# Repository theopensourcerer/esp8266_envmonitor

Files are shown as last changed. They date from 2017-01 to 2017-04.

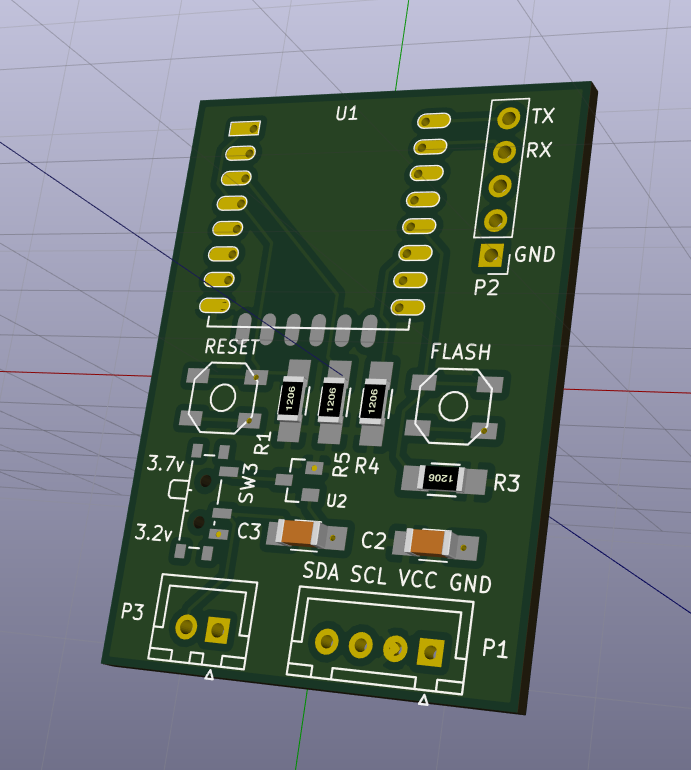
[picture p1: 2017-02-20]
pcb/environment-monitor-1.4.png

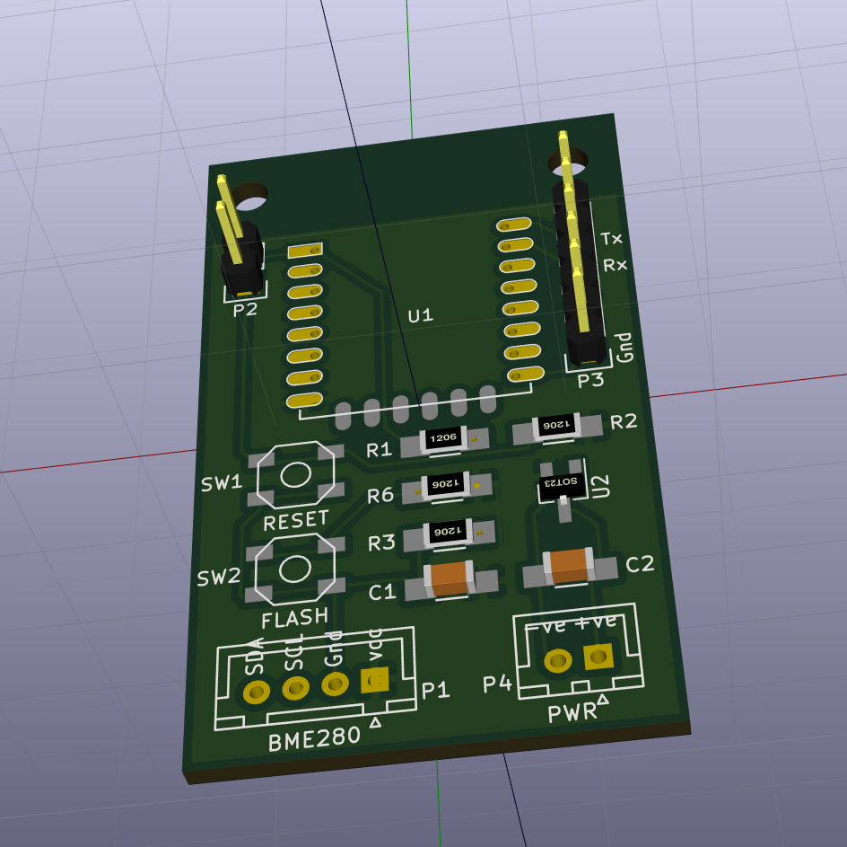
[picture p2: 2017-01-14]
pcb/environment-monitor-1.2.png

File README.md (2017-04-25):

# ESP8266 Environment Monitor

## Table of Contents
* [Summary](#summary)
* [Case](#case)
* [Hardware](#hardware)
* [Code](#code)
* [License](#license)

## Summary
This is a personal project to build an Environment Monitor for my Polytunnel where I mostly grow chillies.

The project consists of three parts: the case to hold the monitor, the hardware (PCB and Sensor(s) etc.) and the software.

## Case

The case is designed in OpenSCAD and is suitable for printing on a 3D Printer. I am very pleased with the results of the design. Please feel free to use and improve - within the terms of the license of course.

## Hardware

The Schematic and PCB are designed in KiCAD. The board has not yet been fully tested. In fact the board has several flaws, some of which do not seem to be problematic, but one that caused me a long headache. The pin called CH_PD on my board needed to be pulled high. I have tacked a 4.7k resistor to the back of the board. Without this, the board would not start. Oddly though, in all of the previous ESP8266 designs I have worked on (mostly on vero or breadboard) I have not had to pull this pin high at all. Please be __warned__ if you want to use my design.

As of version 1.4 of the schematic and PCB the above issue should be fixed. I've not tested it but the board has undergone a fairly major redesign which includes an on-board switch to support for running directly of LiFePO4 batteries at 3.2v or, via the Regulator off normal 3.7v Li-ion.

## Code

The software for the ESP8266 is in this directory. It is fairly simple C code. The config.h file contains user-defined parameters.
The ESP8266 code works like this: On power up the ESP attempts to connect to the WiFi network. If successful it then attempts to 
read the data back from the BME280 which provides, Temperature, Humidity and Pressure information. If the BME is read successfully
the data is formatted and sent to the MQTT broker. The ESP8266 also sends infomration about it's supply voltage and the time it 
took to run this code loop. Finally the code puts the ESP into "Deep Sleep" for a preconfigured period.

## License

The software is GPL, the OpenSCAD design of the case is Creative Commons Attribution-ShareAlike 4.0 International and the 
electronic designs are licenced using the Solderpad Hardware License version 0.51

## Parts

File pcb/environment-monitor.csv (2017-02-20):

Reference | Value | Footprint | Datasheet | BOM
U1 | ESP-12F | ESP8266:ESP-12E
R1 | 4.7k | Resistors_SMD:R_1206_HandSoldering
R3 | 4.7k | Resistors_SMD:R_1206_HandSoldering
C2 | 10uF | Capacitors_SMD:C_1206_HandSoldering
P1 | BME280 | Connectors_JST:JST_XH_B04B-XH-A_04x2.50mm_Straight
P3 | PWR | Connectors_JST:JST_XH_B02B-XH-A_02x2.50mm_Straight
SW1 | RESET | switches:SKQGAFE010_Switch
SW2 | FLASH | switches:SKQGAFE010_Switch
R4 | 4.7k | Resistors_SMD:R_1206_HandSoldering
C3 | 1uF | Capacitors_SMD:C_1206_HandSoldering
U2 | MCP1700T | smd-semi:SOT-23 |  | IC MICROCHIP MCP1700T-vv02E/TT
R5 | 4.7k | Resistors_SMD:R_1206_HandSoldering
SW3 | Switch_SPDT_x2 | switches:SW_SPDT_PCM12
P2 | SERIAL | Pin_Headers:Pin_Header_Straight_1x05_Pitch2.54mm

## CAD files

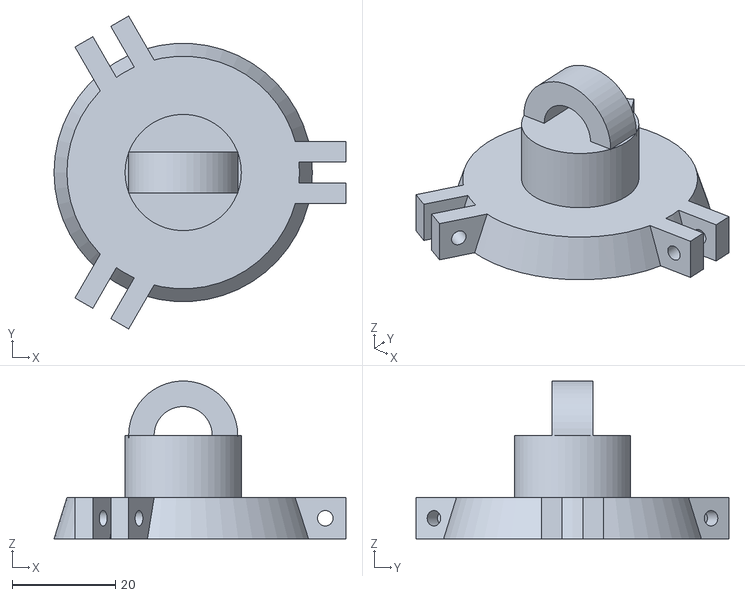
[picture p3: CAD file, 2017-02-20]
case/grabber-top.stl
56.5 x 60.6 x 30.5

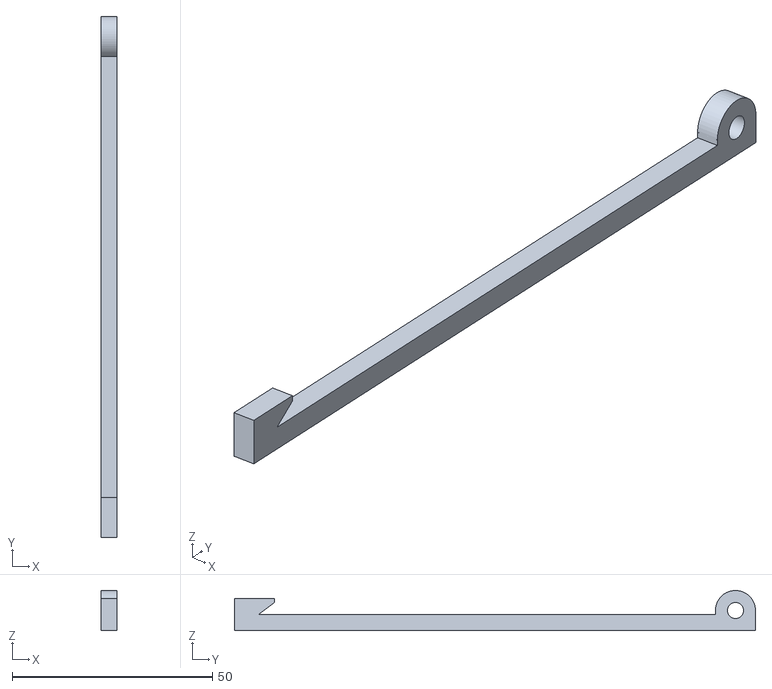
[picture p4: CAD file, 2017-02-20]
case/grabber-leg.stl
4.00 x 130.0 x 10.0

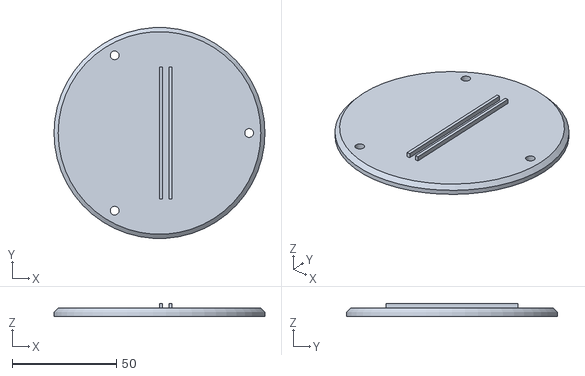
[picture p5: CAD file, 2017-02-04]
case/base.stl
101.0 x 100.8 x 6.00

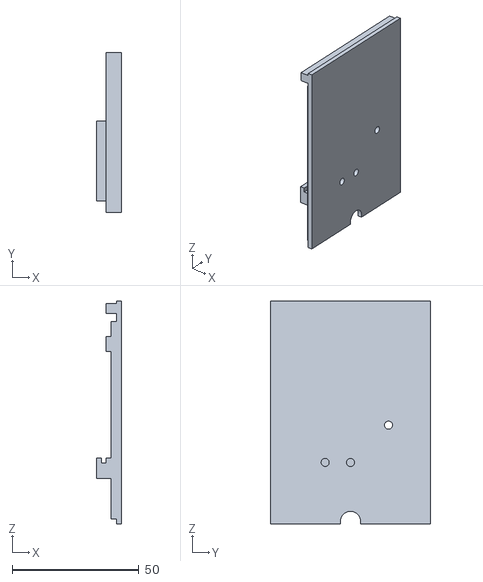
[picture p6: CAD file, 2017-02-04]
case/mounting-plate.stl
9.75 x 63.0 x 88.0

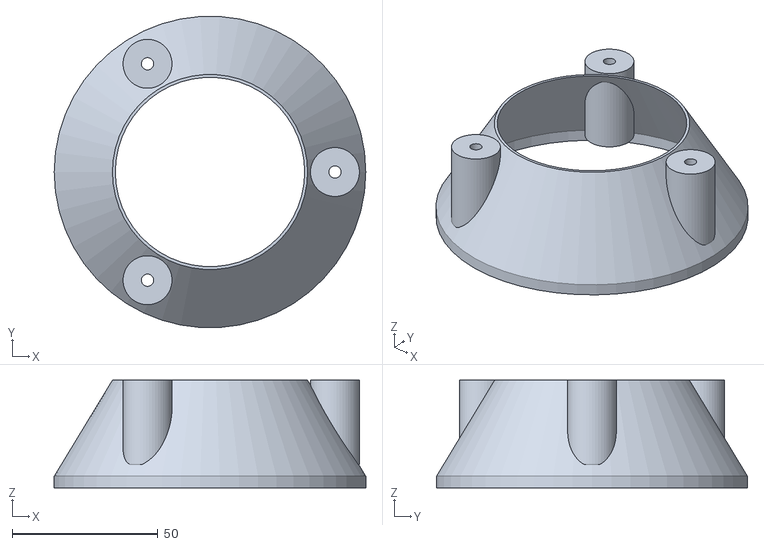
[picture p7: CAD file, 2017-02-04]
case/other-sections.stl
107.0 x 106.8 x 37.0

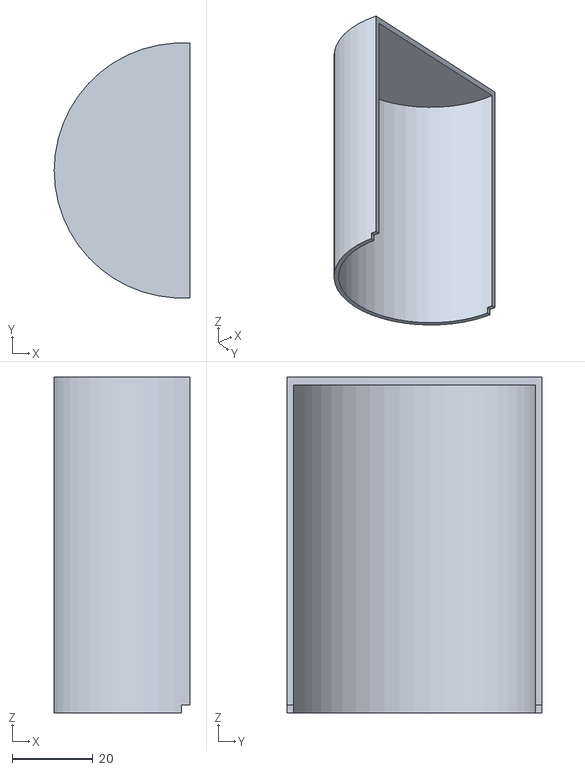
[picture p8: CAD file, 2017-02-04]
case/internal-case.stl
33.5 x 62.9 x 83.0

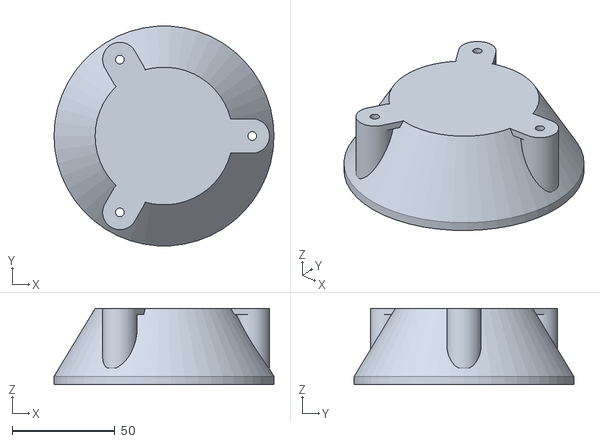
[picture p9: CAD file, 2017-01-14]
case/top-section.stl
107.0 x 106.8 x 37.0

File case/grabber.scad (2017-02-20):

/*
 * Grabber
 */
$fn=50;
width = 4;
depth = 4;
length = 120;

bracketLength=13;
topdia = 45;
bottomdia = 50;

top();

leg();
module leg() {
    cube([width,length,depth]);
    translate([0,,0,depth]) {
        gripper();
    }
    translate([0,length,0]) {
        brace();
    }
 }
 
module gripper() {
    gripper=10;
    difference() {
        cube([width,gripper,depth]);
        translate([0,gripper-depth,0]) {
            prism(width,depth,depth-1);
        }
    }
}

module brace() {
    brace=10;
    difference() {
        union() {
            translate([0,brace/2,brace/2]) {
                rotate([0,90,0]) cylinder(d=10,h=depth);
            }
            cube([width,brace,brace/2]);
        }
        translate([0,brace/2,brace/2]) {
            rotate([0,90,0]) cylinder(d=width,h=depth*2);
        }
    }
}

module top() {
    height=depth*2;
    cylinder(d1=bottomdia,d2=topdia,h=height);
    for(r=[0,120,240]) rotate([0, 0, r]) translate([topdia/2-depth,0, 0]) bracket();
    hook();
}

module bracket() {
    translate([0,-(depth+(depth/2)),0]) {
        difference(){
            cube([bracketLength,depth*3,depth*2]);
            translate([0,depth,0]) {
                cube([bracketLength,depth,depth*2]);
            }
            translate([bracketLength-depth,depth*3.5,depth]) {
                rotate([90,0,0]) cylinder(d=3,h=depth*4);
            }
        }
    }
}

module prism(l, w, h){
    polyhedron(
        points=[[0,0,0], [l,0,0], [l,w,0], [0,w,0], [0,w,h], [l,w,h]],
        faces=[[0,1,2,3],[5,4,3,2],[0,4,5,1],[0,3,4],[5,2,1]]
    );
}

module hook() {
    cylinder(d=topdia/2,h=depth*5);
    translate([0,depth,depth*5]) {
        difference() {
            rotate([90,0,0]) cylinder(d=topdia/2.13,h=depth*2);
            rotate([90,0,0]) cylinder(d=topdia/4,h=depth*2.1);
        }
    }
}

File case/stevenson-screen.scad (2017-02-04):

/**
 * Design for a Stevenson Screen type container
 *
 * License:  Attribution-ShareAlike 4.0 International 
 * https://creativecommons.org/licenses/by-sa/4.0/
 *
 * Based on an original idea from http://jeelabs.net/boards/6/topics/1857
 *
**/


/*
 * makeBase:base,
   makeBottom:bottom,
   makeMiddle:middle,
   makeTop,top,
   makeAll:all
 *
**/
part = "makeAll"; 

$fn=50;
id=65;
od=105;
sectionheight=33;
walls=2;
bolt=4.2;
top_depth=walls+1;
pillar_radius = (id/2)+(bolt*walls)+walls;
pillarheight=(sectionheight-(walls*2));
containerHeight = 83;

nutSize = 6;
nutHeight = 3;
nutThread = 3.2;
boltLength = 8;

pcbWidth = 31.5;
pcbHeight = 52.5;
pcbThickness = 1.75;
pcbHoleCentres = 24;

// Base
//base();

mountingPlate();
/*
internalCase();

// Bottom Section
color("DeepSkyBlue", 0.5) translate([0,0,walls*2]) {
    difference() {
        section();
        translate([pillar_radius,0,0]) {
            bolthole();        }
        translate([-pillar_radius/2,((pillar_radius)*sin(120)),0]) {
            bolthole();
        }
        translate([-pillar_radius/2,-((pillar_radius)*sin(120)),0]) {
            bolthole();
        }
    }
}

//Middle Section
color("DeepSkyBlue", 0.5) translate([0,0,sectionheight]) {
    difference() {
        section();
        translate([pillar_radius,0,0]) {
            bolthole();        }
        translate([-pillar_radius/2,((pillar_radius)*sin(120)),0]) {
            bolthole();
        }
        translate([-pillar_radius/2,-((pillar_radius)*sin(120)),0]) {
            bolthole();
        }
    }
}


// Top Section
%translate([0,0,sectionheight*2-(walls*2)]) {
    difference() {
        section();
        translate([pillar_radius,0,0]) {
            bolthole();
        }
        translate([-pillar_radius/2,((pillar_radius)*sin(120)),0]) {
            bolthole();
        }
        translate([-pillar_radius/2,-((pillar_radius)*sin(120)),0]) {
            bolthole();
        }
    }
}

// Top
color("DeepSkyBlue", 0.5) translate([0,0,sectionheight*3-(top_depth*2+1)]) top();
*/
module section() {
    difference() {
        cylinder(sectionheight,(od+walls)/2,(id+walls)/2 );
        cylinder(sectionheight,(od/2),(id/2));
    }
    // Skirt
    translate([0,0,-walls*2]) {
        difference() {
            cylinder(walls*2,(od+walls)/2,(od+walls)/2);
            cylinder(walls*2,od/2,od/2);
        }
    }
    translate([pillar_radius,0,0]) {
         pillar();
    }
    translate([-pillar_radius/2,((pillar_radius)*sin(120)),0]) {
        pillar();
    }
    translate([-pillar_radius/2,-((pillar_radius)*sin(120)),0]) {
        pillar();
    }    
}

module pillar() {
    translate([0,0,walls*2]) {
        difference(){
            cylinder(pillarheight,bolt*walls, bolt*walls);
            bolthole();
        }
    }
}

module bolthole() {
    cylinder(pillarheight,bolt/2,bolt/2);
}

module base() {
    base_thickness=walls;
    difference() {
        union() {
            cylinder(base_thickness,(od-4)/2,(od-4)/2);
            translate([0,0,base_thickness]) {
                cylinder(base_thickness,(od-4)/2,(od-8)/2);
            }
            translate([0,-((id-walls)/2),base_thickness*2]) divider();
        }
        translate([pillar_radius,0,0]) {
            bolthole();
        }
        translate([-pillar_radius/2,((pillar_radius)*sin(120)),0]) {
            bolthole();
        }
        translate([-pillar_radius/2,-((pillar_radius)*sin(120)),0]) {
            bolthole();
        }
    }
}

module top() {
    cylinder(top_depth,(id+walls)/2,(id+walls)/2);
    translate([pillar_radius,0,0]) {
        lobe();
    }
    translate([-pillar_radius/2,((pillar_radius)*sin(120)),0]) {
        rotate(120) lobe();
    }
    translate([-pillar_radius/2,-((pillar_radius)*sin(120)),0]) {
        rotate(-120) lobe();
    }
    translate([0,-((id-walls)/2),top_depth-(walls*2)]) divider();
}

module lobe() {
    difference(){
        hull() {
            cylinder(top_depth,bolt*walls, bolt*walls);
            translate([-bolt*walls,0,0]) {
                cylinder(top_depth,bolt*walls, bolt*walls);
            }
        }
        cylinder(top_depth,bolt,bolt);
    }
}
module divider() {
    widthOfBaseBlock=walls*3;
    difference() {
        cube([widthOfBaseBlock,id-walls,walls]);
        translate([(widthOfBaseBlock/4),0,0]){
            cube([walls+(walls/2),id-walls,walls*2]);
        }
    }
}

module mountingPlate() {
    difference() {
        union() {
            // Plate
            translate([walls,-((id-walls)/2), walls*2]) {
                cube([walls,id-walls,(pillarheight*3)+(walls/2)]);
            }
            // External top bar
            translate([-walls,-((id-walls)/2), containerHeight+(walls*2)]) {
                cube([walls*2, id-walls,walls*2]);
            }
            // Side bar
            translate([0,-((id-walls)/2)+walls,walls*3]) {
                cube([walls,walls,containerHeight-walls*2.5]);
            }
            // Side bar
            translate([0,((id-walls)/2)-(walls*2),walls*3]) {
                cube([walls, walls,containerHeight-walls*2.5]);
            }
            // Internal top bar
            translate([0,-(id-(walls*5))/2,containerHeight-(walls-1)]) {
                cube([walls,id-(walls*5), walls]);
            }
            // PCB top mount
            translate([walls,-27,(walls*2)+74]) {
                rotate([0,180,0]) {
                    pcbTopMount();
                }
            }
            translate([walls,-27,(walls*2)+(74-50)]) {
                rotate([0,180,0]) {
                    pcbBottomMount();
                }
            }
        }
        // Battery case mounting hole
        translate([walls-1,((id-walls)/2)-(walls*2)-11-(3/2),(walls*2)+39]) {
            rotate([0, 90,0]) {
                cylinder(d=3.2,h=walls+2);
            }
        }
        // Sensor cable access
        translate([walls-1,0,5]) {
            rotate([0,90,0]){
                cylinder(d=8,h=walls+2);
            }
        }
        // BME280 mounting holes
        translate([-1,0,(walls*2)+24.3]) {
            rotate([0,90,0]) {
                cylinder(d=3.2,h=walls+2);
                bolt(nutSize,nutHeight, nutThread,boltLength);

                translate([0,-10,0]) {
                    cylinder(d=3.2,h=walls+2);
                bolt(nutSize,nutHeight, nutThread,boltLength);

                }
            }
        }
    }
}

module internalCase() {
    odia = id-walls;
    idia = id-(walls*2.5);
    translate([0, 0, walls*2]) {        
        difference() {
            cylinder(h=containerHeight,d1=odia,d2=odia);
            cylinder(h=containerHeight-walls,d1=idia,d2=idia);
            translate([walls,-id/2,0]) {
                cube([id/2, id, containerHeight]);
            }
            translate([0,-odia/2,0]) {
                cube([walls,odia,walls]);
            }  
        }
    }
}

module pcbTopMount() {
    diff = (pcbWidth-pcbHoleCentres) / 2;
    difference() {
        cube([nutHeight+1,pcbWidth,nutSize]);
        translate([0,diff,(nutThread/2)]){
            rotate([0,90,0]) {
                bolt(nutSize,nutHeight, nutThread,boltLength,true);
            }
        }
        translate([0,(pcbWidth-diff),(nutThread/2)]){
            rotate([0,90,0]) {
                bolt(nutSize,nutHeight, nutThread,boltLength, true);
            }
        }
    }
}

module pcbBottomMount() {
        translate([0,0,-2]) {
            cube([nutHeight+1,pcbWidth,nutSize+2]);
        }
        translate([nutHeight+1,0,0]) {
            cube([pcbThickness,pcbWidth,nutSize]);
        }
        translate([nutHeight+1+pcbThickness,0,-2]) {
            cube([walls,pcbWidth,nutSize+2]);
        }
}

// Nut
module nut(width,height,thread) {
    difference() {
        cylinder(d=width/(cos(180/6)), h=height, $fn=6);
        translate([0,0,-0.5]) {
            cylinder(d=thread,h=height+1);
        }
    }
}

module bolt(width,height,thread,length,hull) {
    cylinder(d=width/(cos(180/6)), h=height, $fn=6);
    if(hull) {
        hull(){
            translate([0,0,height]) {
                cylinder(d=thread,h=length);
            }
            translate([thread,0,height]) {
                cylinder(d=thread,h=length);
            }
        }
    } else {
        translate([0,0,height]) {
            cylinder(d=thread,h=length);
        }
    }
}

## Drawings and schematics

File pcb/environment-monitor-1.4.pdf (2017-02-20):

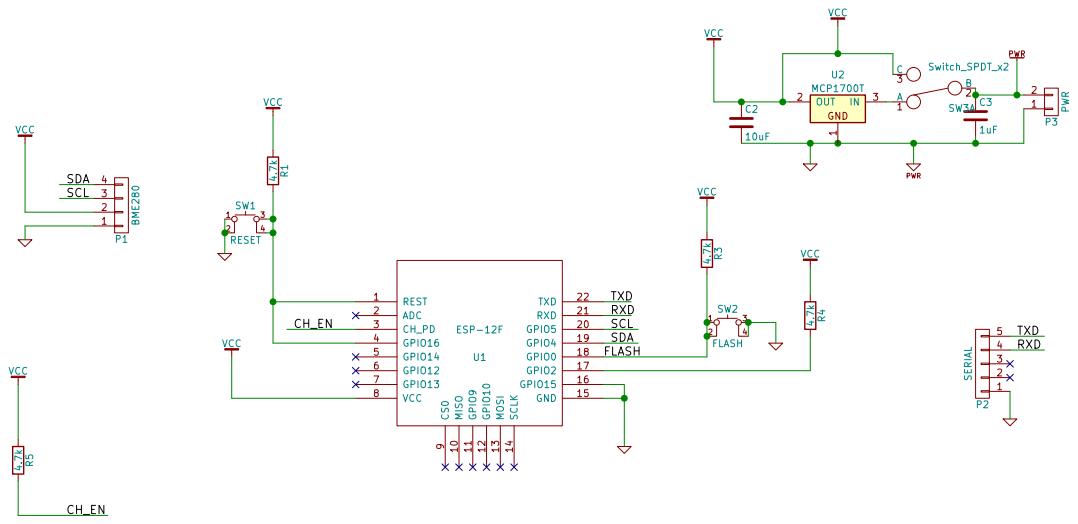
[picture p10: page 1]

9 MISO 10 GPIO5 20 GPIO9 11 RXD 21 GPIO10 12 TXD 22 MOSI 13 SCLK 14 GND 15 GPIO15 16 GPIO2 17 GPIO0 18 GPIO4 19 U1 ESP-12F R1 4.7k R3 4.7k C2

Contact: alanslists@gmail.com
Id: 1/1 Title: Environment Monitor File: environment-monitor.sch Sheet: / Solderpad Hardware License version 0.51

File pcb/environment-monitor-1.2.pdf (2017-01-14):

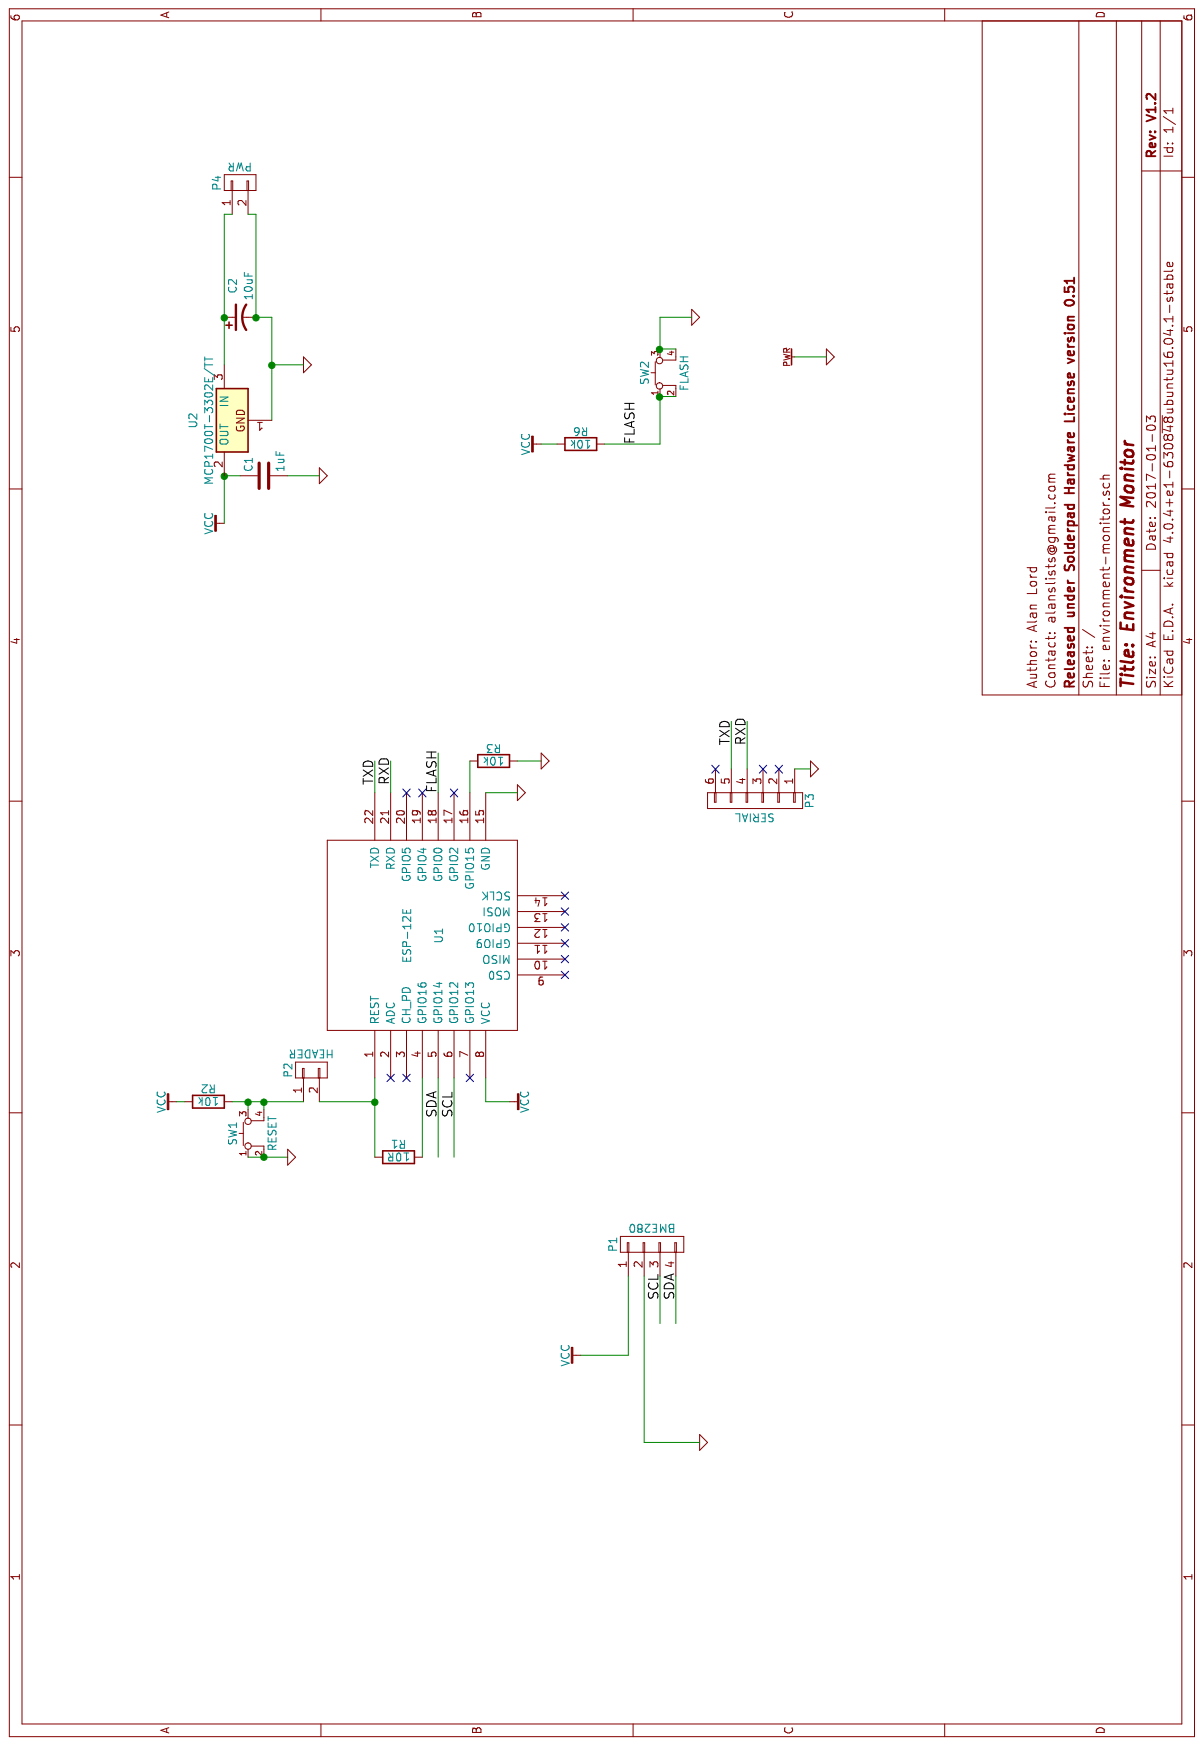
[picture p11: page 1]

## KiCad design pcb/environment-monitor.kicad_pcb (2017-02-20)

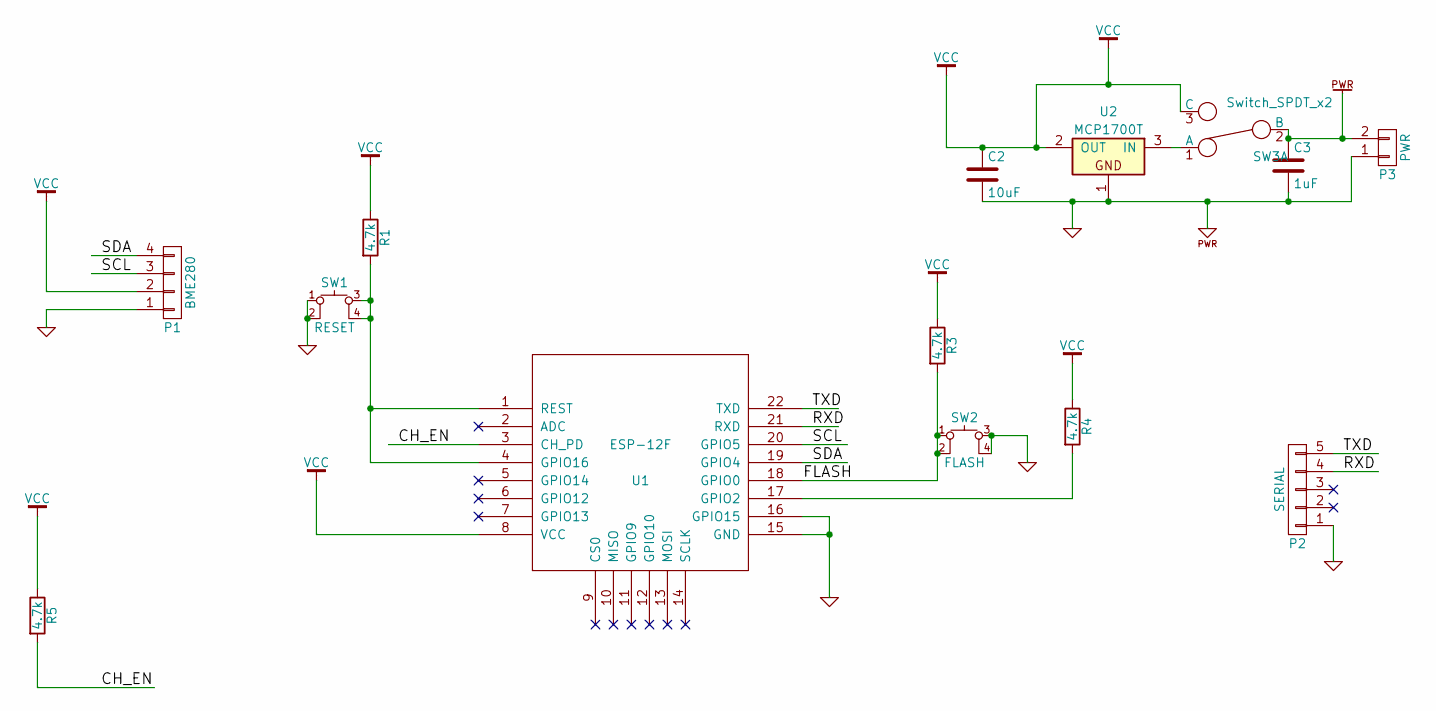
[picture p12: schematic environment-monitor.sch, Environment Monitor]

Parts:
C2: 10uF; C_1206_HandSoldering
C3: 1uF; C_1206_HandSoldering
P1: BME280; JST_XH_B04B-XH-A_04x2.50mm_Straight
P2: SERIAL; Pin_Header_Straight_1x05_Pitch2.54mm
P3: PWR; JST_XH_B02B-XH-A_02x2.50mm_Straight
R1, R3, R4, R5: 4.7k; R_1206_HandSoldering
SW1: RESET; SKQGAFE010_Switch
SW2: FLASH; SKQGAFE010_Switch
SW3: Switch_SPDT_x2; SW_SPDT_PCM12
U1: ESP-12F; ESP-12E
U2: MCP1700T; SOT-23

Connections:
/CH_EN: R5.2, U1.3 (CH_PD)
/FLASH: R3.2, SW2.1, SW2.2, U1.18 (GPIO0)
/RXD: P2.4, U1.21 (RXD)
/SCL: P1.3, U1.20 (GPIO5)
/SDA: P1.4, U1.19 (GPIO4)
/TXD: P2.5, U1.22 (TXD)
GND: C2.2, C3.2, P1.1, P2.1, P3.1, SW1.1, SW1.2, SW2.3, SW2.4, U1.15 (GND), U1.16 (GPIO15), U2.1
unnamed: C3.1, P3.2, SW3.2 (B)
unnamed: R1.2, SW1.3, SW1.4, U1.1 (REST), U1.4 (GPIO16)
unnamed: R4.2, U1.17 (GPIO2)
unnamed: SW3.1 (A), U2.3 (IN)
VCC: C2.1, P1.2, R1.1, R3.1, R4.1, R5.1, SW3.3 (C), U1.8 (VCC), U2.2 (OUT)

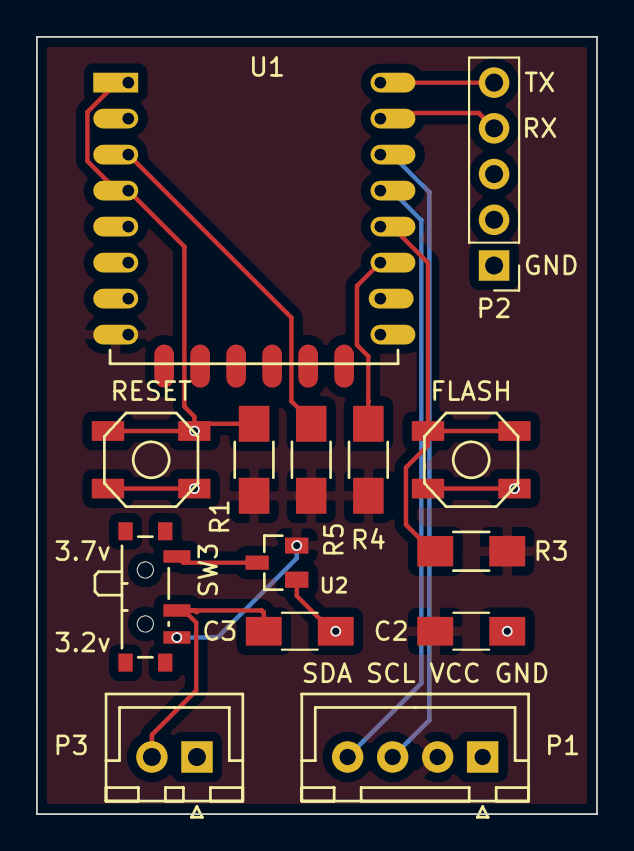
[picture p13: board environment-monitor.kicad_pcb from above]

Board: 2 copper layers, 31.1 x 43.2 mm, 14 parts (0 on the bottom side), 12 nets.

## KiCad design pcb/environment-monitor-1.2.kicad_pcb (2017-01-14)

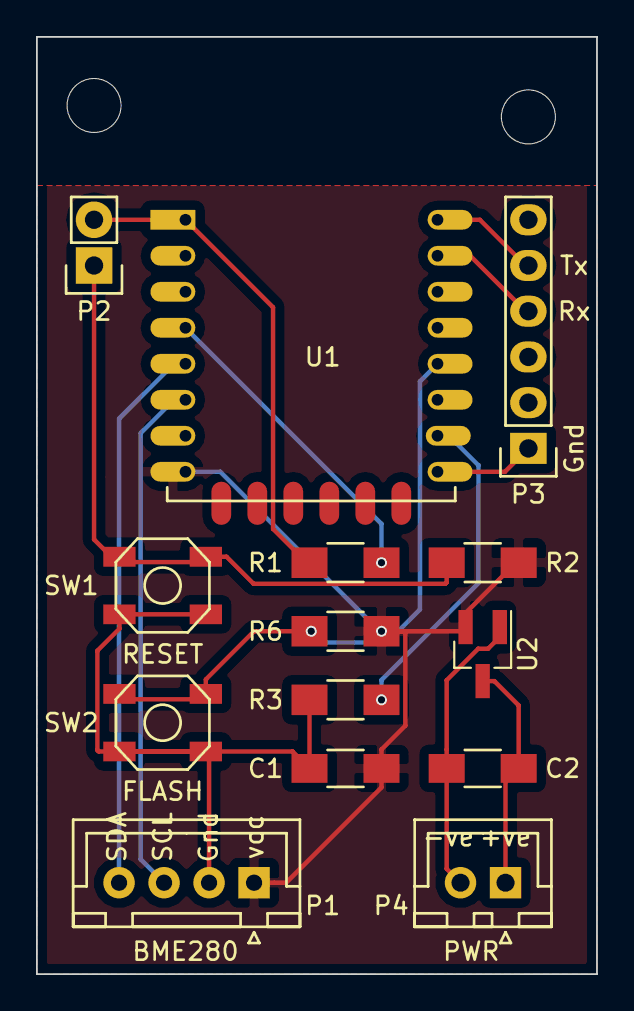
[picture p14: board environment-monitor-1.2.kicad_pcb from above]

Board: 2 copper layers, 31.1 x 52.1 mm, 14 parts (0 on the bottom side), 12 nets.

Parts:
C1: 1uF; C_1206_HandSoldering
C2: 10uF; C_1206_HandSoldering
P1: BME280; JST_XH_B04B-XH-A_04x2.50mm_Straight
P2: HEADER; Pin_Header_Straight_1x02
P3: SERIAL; Pin_Header_Straight_1x06
P4: PWR; JST_XH_B02B-XH-A_02x2.50mm_Straight
R1: 10R; R_1206_HandSoldering
R2, R3, R6: 10k; R_1206_HandSoldering
SW1: RESET; SKQGAFE010_Switch
SW2: FLASH; SKQGAFE010_Switch
U1: ESP-12E
U2: MCP1700T-3302E/TT; SOT-23_Handsoldering

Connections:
/FLASH: R6.2, SW2.1, SW2.2, U1.18
/RXD: P3.4, U1.21
/SCL: P1.3, U1.6
/SDA: P1.4, U1.5
/TXD: P3.5, U1.22
GND: C1.2, C2.2, P1.2, P3.1, P4.2, R3.2, SW1.1, SW1.2, SW2.3, SW2.4, U1.15, U2.1
unnamed: C2.1, P4.1, U2.3
unnamed: P2.1, R2.2, SW1.3, SW1.4
unnamed: P2.2, R1.1, U1.1
unnamed: R1.2, U1.4
unnamed: R3.1, U1.16
VCC: C1.1, P1.1, R2.1, R6.1, U1.8, U2.2

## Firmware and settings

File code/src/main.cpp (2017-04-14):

/*
Environment Monitor

For the Espressif ESP8266

Uses MQTT and a Bosch BME280 Sensor to read and transmit Temprature, Hunidity and
Air pressure to an MQTT Broker.

This code was written and tested using the PlatformIO IDE and the ESP8266-12F
module.

Ideas and code from various soruces:
https://github.com/chaeplin/esp8266_and_arduino
https://twitter.com/jpwsutton,
https://github.com/finitespace/BME280

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
This code is licensed under the GNU LGPL and is open for ditrbution
and copying in accordance with the license.
This header must be included in any derived code or copies of the code.

(C) Alan Lord 2017
*/
#include "config.h"

#include <ESP8266WiFi.h>
#include <PubSubClient.h>
#include <BME280I2C.h>
#include <Wire.h>
#include <ArduinoJson.h>

// Not sure why this is necessary but the BME280I2C won't compile without it.
#include <SPI.h>

// Set up ESP8266 ADC for voltage read
ADC_MODE(ADC_VCC);
float vcc;

// BME280
bool metric = true; // Want 'C not 'F
float temp(NAN), hum(NAN), pres(NAN);
uint8_t pressureUnit(1); // unit: B000 = Pa, B001 = hPa, B010 = Hg, B011 = atm, B100 = bar, B101 = torr, B110 = N/m^2, B111 = psi

// Timer placeholders
unsigned long startMills = 0;

// Function Prototypes
void readBME();
void setup_wifi();
void reconnect();
void publishJSON();
void goingToSleep();
// End Prototypes

// Begin code
WiFiClient espClient;
PubSubClient client(espClient);
BME280I2C bme;

void setup() {
  startMills = millis();
  vcc = ESP.getVcc();
  Serial.begin(115200);
  while(!bme.begin()) {
    Serial.println("Could not find BME280I2C sensor!");
    Serial.println("Going to sleep");
    goingToSleep();
  }
  setup_wifi();
  client.setServer(MQTT_SERVER, 1883);
}

void setup_wifi() {
  //delay(10);
  // We start by connecting to a WiFi network
  if (DEBUG_PRINT) {
    Serial.println();
    Serial.print("Connecting to ");
    Serial.println(WIFI_SSID);
  }
  WiFi.begin(WIFI_SSID, WIFI_PASSWORD);

  while (WiFi.status() != WL_CONNECTED) {
    delay(500);
    Serial.print(".");
    if (millis() - startMills > 15000) {
      if (DEBUG_PRINT) {
        Serial.println("Taken too long to connect to WiFi. Going to sleep");
      }
      goingToSleep();
    }
  }

  if (DEBUG_PRINT) {
    Serial.println("");
    Serial.println("WiFi connected");
    Serial.println("IP address: ");
    Serial.println(WiFi.localIP());
  }
}

void loop() {
  if (!client.connected()) {
    reconnect();
  }

  readBME();

  if(temp && hum && pres) {
    if (DEBUG_PRINT) {
      Serial.print("Read BME280. Publish message: ");
    }
    publishJSON();
  }
  goingToSleep();
}

void publishJSON() {
  if (client.connected()) {
    StaticJsonBuffer<175> jsonBuffer;
    JsonObject& root = jsonBuffer.createObject();
    JsonArray& payload = root.createNestedArray("payload");
    JsonObject& data = payload.createNestedObject();
    data["sensorid"] = SENSORNAME;
    data["temp"] = temp;
    data["hum"] = hum;
    data["pres"] = String(pres, 2);
    data["vcc"] = vcc/1000;
    data["cycletime"] = millis() - startMills;
    if (DEBUG_PRINT) {
      Serial.print("Sending payload: ");
      root.prettyPrintTo(Serial);
    }

    char buffer[150];
    root.printTo(buffer, sizeof(buffer));
    if (client.publish(TOPIC, buffer));
      if (DEBUG_PRINT) {
        Serial.print("Published OK  --> ");
        Serial.println(millis() - startMills);
      }
    } else {
      if (DEBUG_PRINT) {
        Serial.print("Publish failed --> ");
        Serial.println(millis() - startMills);
      }
    }
}

void reconnect() {
  // Loop until we're reconnected
  while (!client.connected()) {
    if (DEBUG_PRINT) {
      Serial.print("Attempting MQTT connection...");
    }
    // Attempt to connect
    if (client.connect("ENVMonitor")) {
      if (DEBUG_PRINT) {
        Serial.println("Connected");
      }
    } else {
      if (DEBUG_PRINT) {
        Serial.print("Failed to connect. State = ");
        Serial.print(client.state());
        Serial.println(" Retry in 2 seconds");
      }
      // Wait 2 seconds before retrying
      delay(2000);
    }
  }
}

void readBME() {
  bme.read(pres, temp, hum, pressureUnit, metric);
  if (DEBUG_PRINT) {
    Serial.print("Temp: ");
    Serial.print(temp);
    Serial.print(" Humidity: ");
    Serial.print(hum);
    Serial.print(" Pressure: ");
    Serial.print(pres);
    Serial.println();
  }
}

void goingToSleep() {
  // All Good
  if (DEBUG_PRINT) {
    Serial.print("About to go to sleep: Time taken to complete cycle: ");
    Serial.println(millis() - startMills);
  }
  client.disconnect();
  yield();
  WiFi.disconnect();
  WiFi.mode(WIFI_OFF);
  WiFi.forceSleepBegin();
  ESP.deepSleep(deep_sleep, DS_MODE);
  //ESP.deepSleep(0);
  delay(250);
}

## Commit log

2017-01-23 Update README.md
    Add information about the CH_PD pin.
2017-02-04 Updates to Stevenson Screen case design.
    [base.stl, internal-case.stl, mounting-plate.stl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]
2017-02-20 Update Schematic and PCB to new design
    [environment-monitor-1.2.kicad_pcb, environment-monitor-1.4.kicad_pcb, environment-monitor.csv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]
2017-02-20 Added 3D image of PCB
2017-02-20 Add design for grabber to suspend the case
    [grabber-leg.stl, grabber-top.stl, grabber.scad]
2017-04-14 Fixed issue with Pressure reading (float/string). Added static Sensorname parameter
    [main.cpp]

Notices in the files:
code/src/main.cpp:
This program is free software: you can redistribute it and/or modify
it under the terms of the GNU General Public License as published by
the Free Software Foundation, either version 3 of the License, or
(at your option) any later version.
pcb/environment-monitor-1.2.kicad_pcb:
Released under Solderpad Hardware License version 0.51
